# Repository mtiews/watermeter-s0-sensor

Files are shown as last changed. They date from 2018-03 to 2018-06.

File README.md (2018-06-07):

# Watermeter - S0 - Sensor

## Version 1 - with HOA1405-002 reflective sensor

*For this version the Arduino sketch `watermeter` is used.*

Sensor to create electronic impulses from a watermeter.

The HOA1405-002 reflective sensor is mounted to a watermeter, pointing to a rotating disk under water, which has alternating black and reflective areas. The signal from the photo transistor is then read via an analog input of an Atmega328P (maybe a bit oversized). Via Arduino sketch the signal is analyzed and the Atmega328P creates an impulse (5ms) for each black-reflective transition via a digital output.

I'm currently using this sensor together with this [Arduino S0 sensor](https://github.com/mtiews/arduino-s0-sensor), which feeds the data to our Smarthome.py installation. In my Smarthome installation im counting the impulses (for our watermeter 30imp/liter) and display our water consumption in a Web UI and a MagicMirror.

Sensor is based on:
* a HOA1405-002 Honeywell reflective sensor
* a watermeter mount for the sensor (STL file for 3D printing)
* an Atmega328P based circuit to read the sensor signals and generate the impulses
* an Arduino sketch and
* a simple case for the PCB (STL file for 3D printing).

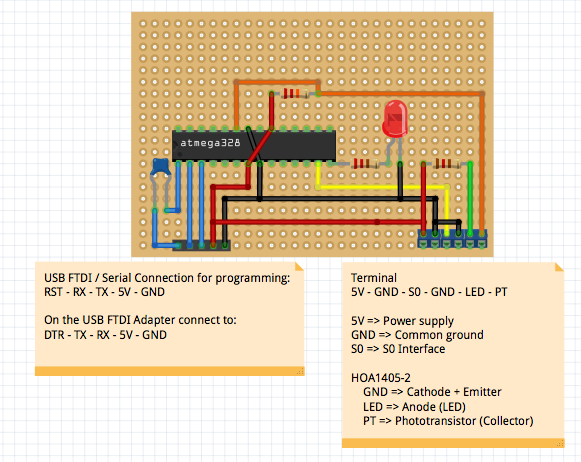
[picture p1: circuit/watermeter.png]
Circuit


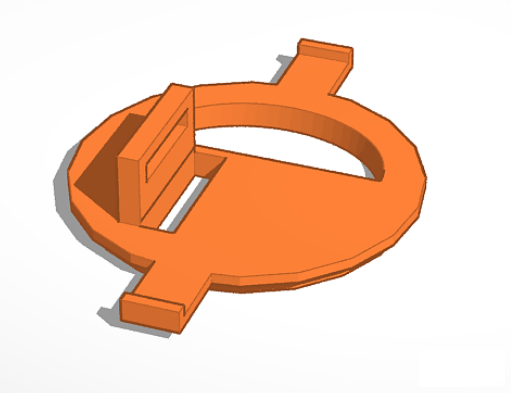
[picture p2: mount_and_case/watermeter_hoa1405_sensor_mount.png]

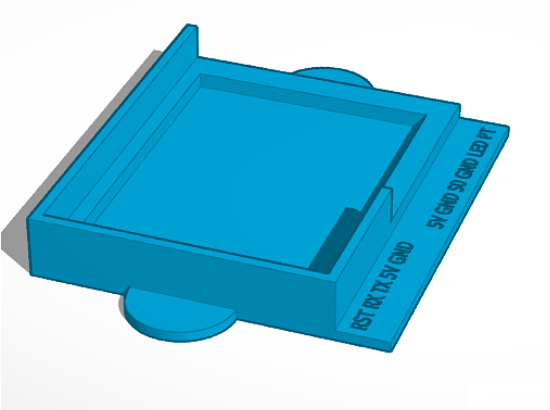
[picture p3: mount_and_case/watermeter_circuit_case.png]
Circuit


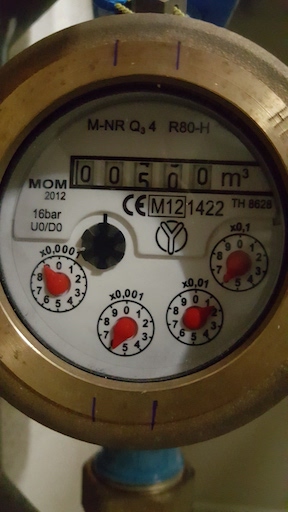
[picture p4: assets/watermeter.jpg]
Watermeter

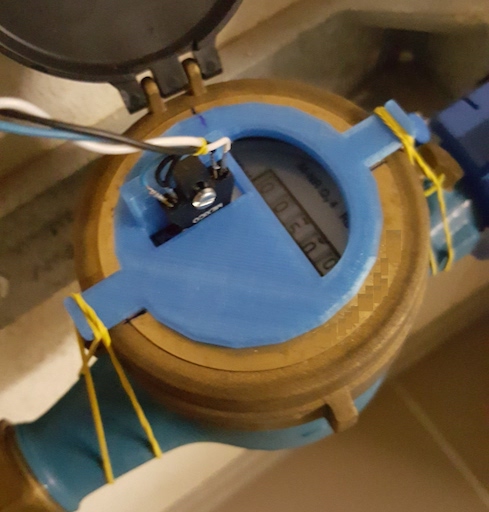
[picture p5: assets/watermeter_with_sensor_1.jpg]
Watermeter

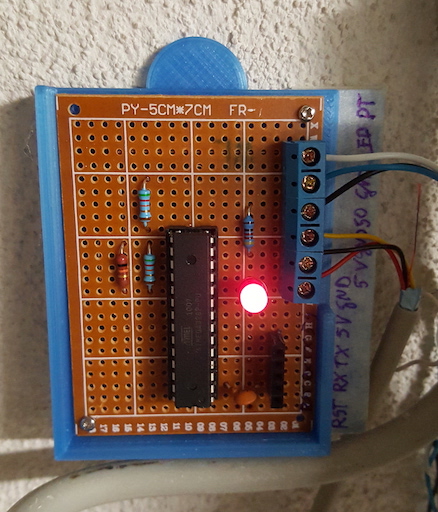
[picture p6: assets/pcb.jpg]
PCB


## Version 2 - with LJ18A3-8-Z/BX inductive sensor

Updated version now using an inductive sensor (NPN) pulling the sensor output to ground. Change was required due to the fact, that the watermeter was changed and the old hardware solution did not work any more!

*For this version the Arduino sketch `watermeter2` is used.*

Required changes:
* sketch `watermeter2` is used
* the inductive sensor is boosted via MT3608 to about 12V, the MT3608 is connected to 5V and ground of the PCB
* the sensor output is connected to the `PT` input
* New designed watermeter mount for inductive sensor

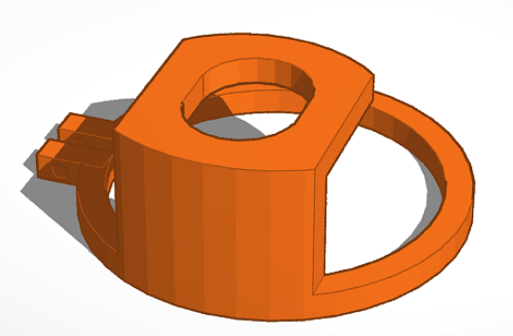
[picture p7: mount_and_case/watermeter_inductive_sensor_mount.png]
Watermeter


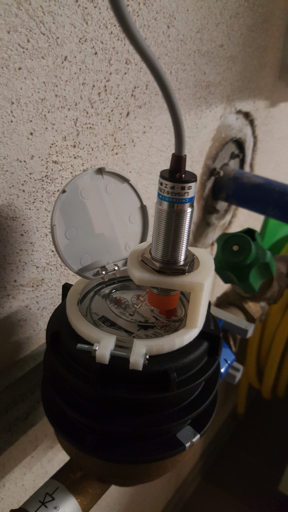
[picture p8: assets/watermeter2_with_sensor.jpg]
Watermeter


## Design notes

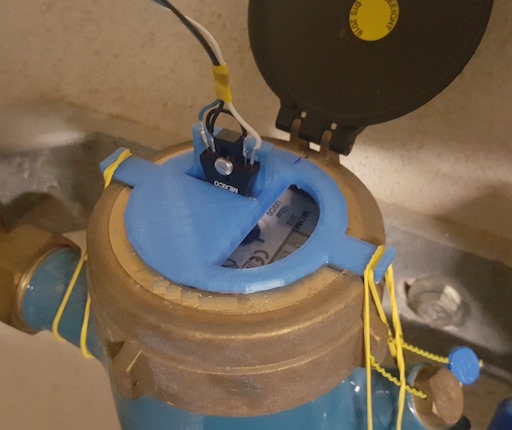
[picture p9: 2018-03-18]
assets/watermeter_with_sensor_2.jpg

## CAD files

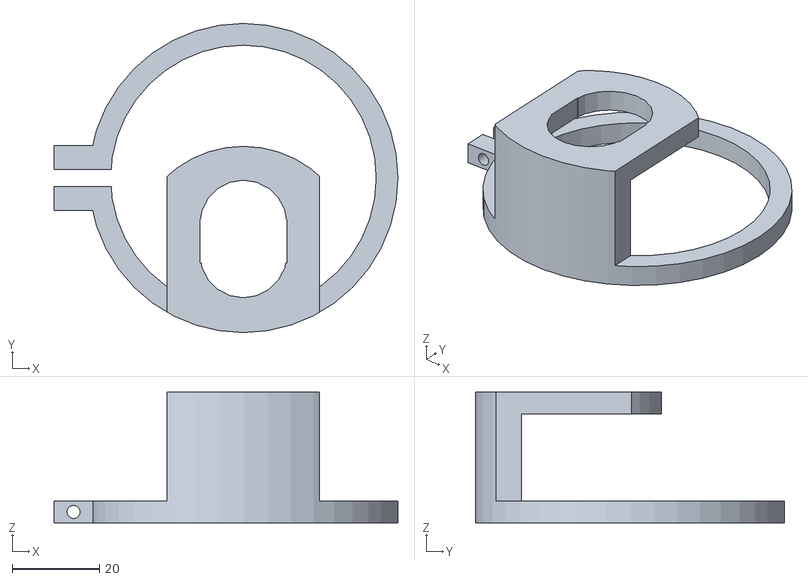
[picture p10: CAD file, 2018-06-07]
mount_and_case/watermeter_inductive_sensor_mount.stl
79.0 x 71.0 x 30.0

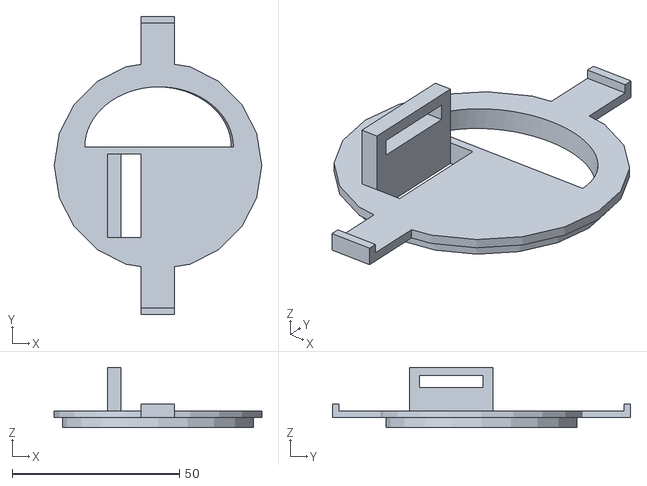
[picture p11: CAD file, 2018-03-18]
mount_and_case/watermeter_hoa1405_sensor_mount.stl
62.0 x 89.0 x 18.0

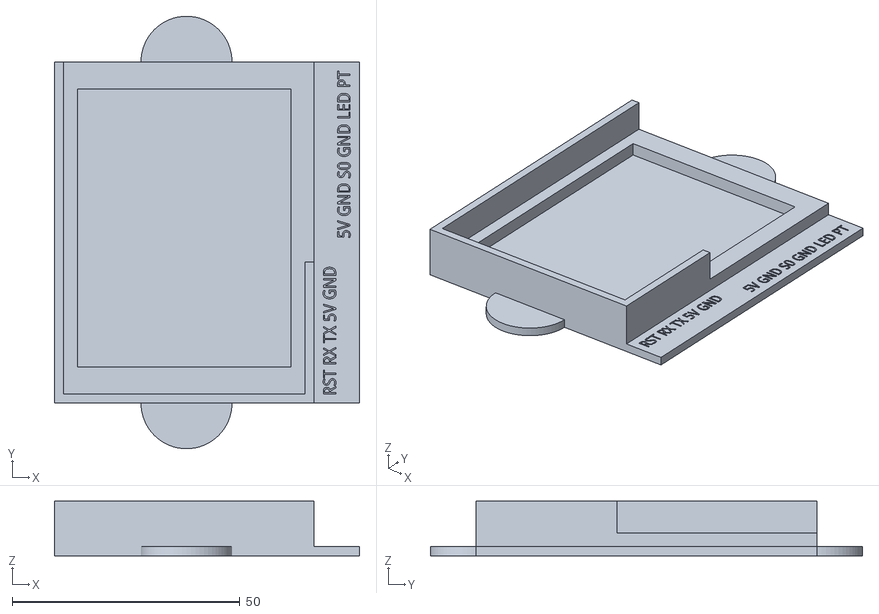
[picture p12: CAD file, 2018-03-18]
mount_and_case/watermeter_circuit_case.stl
67.0 x 95.0 x 12.0

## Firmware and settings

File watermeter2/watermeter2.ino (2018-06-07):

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
// Updated version now using an inductive sensor (NPN) pulling the sensor output to ground
// Change was required due to the fact, that the watermeter was changed and the old solution
// did not work any more!

#define WM_INPUT_PIN A0
#define WM_LED_PIN 8
#define WM_OUTPUT_PIN 7

bool prevPinstate = false;

void setup() {
  Serial.begin(115200);
  pinMode(WM_INPUT_PIN, INPUT_PULLUP);
  pinMode(WM_LED_PIN, OUTPUT);
  pinMode(WM_OUTPUT_PIN, OUTPUT);
}

void loop() {
  readInputAndPulse();
}

void readInputAndPulse() {
  boolean pinstate = digitalRead(WM_INPUT_PIN);

  // ONLY react on state changes 
  // Important: this could be done in an isr as well, but in isrs delay() does not
  // work, so this has to be done then in the main loop with counting millis etc. 
  if(!pinstate && prevPinstate) {
      digitalWrite(WM_OUTPUT_PIN, HIGH); 
      digitalWrite(WM_LED_PIN, HIGH); 
      delay(100);
      digitalWrite(WM_OUTPUT_PIN, LOW);  
      digitalWrite(WM_LED_PIN, LOW); 
  }
  prevPinstate = pinstate;
}

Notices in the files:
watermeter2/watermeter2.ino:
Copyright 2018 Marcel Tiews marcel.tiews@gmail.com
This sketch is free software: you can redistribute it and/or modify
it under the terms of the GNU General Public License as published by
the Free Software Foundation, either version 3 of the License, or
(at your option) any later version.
